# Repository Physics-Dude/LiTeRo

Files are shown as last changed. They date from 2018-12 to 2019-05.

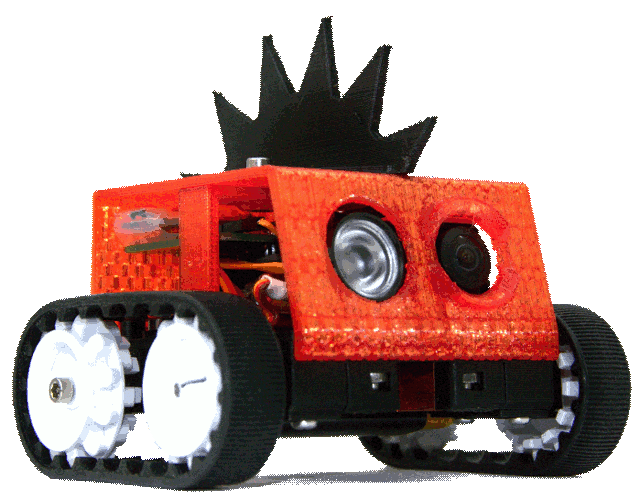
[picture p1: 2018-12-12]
html/robot.png

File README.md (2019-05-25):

# LiTeRo
## LiTeRo, the (Li)ttle (Te)lepresense (Ro)bot  

This python sketch is used in conjunction with phraser.php and litero.html to make a little RasPi-powered rover scoot around and do stuff.

#### Features included by default (Used GPIO pins also listed):
- MJPEG Streamer
  - 160-175deg Wide Angle Camera Module with White/IR LED modules For Raspberry Pi (Banggood)
- RPi.GPIO
  - HG7881 (L9110) Dual Channel Motor Driver (GPIO Pins 17, 18, 22, 27)
  - Navigation LED (2N2222 mod for White/IR LED module) (GPIO Pin 23)
  - Servo control! (Optional, not used by default. Pin 19)
- eSpeak Text-To-Speech
  - LM4871 audio amp conected to GPIO pin #13 (see: PWM1 on GPIO #13 (ALT0) for RasPi Zero W) 
- MinIMU-9 (I2C x2)
- ADS1115 ADC (Refer to Adafruit tutorials for setup) (I2C)
- sSMTP
	
#### Basic operation:
theprogram.py reads from a short text file in RAM (/dev/shm/input.txt) at about 60Hz with parameters that are set at will by a PHP script. The PHP script is being called as the client(s) send in new commands (ex: ./phraser.php?ID=546939&CT=1521479887886&M1=90&M2=90). The client in return gets an XML response that this Python program creates in RAM (/dev/shm/output.txt) along with an ongoing live view from the bot using MJPEG-Streamer. 
  
 LiTeRo by default will speak its local ip address on bootup. It will also guide you through the magnetic compass calibration when mag_calibration.txt is removed before bootup.

#### Things to prepare your Raspberry Pi or Raspberry Pi Zero
- For the Raspberry Pi Zero, you should enable audio out on one of the GPIO pins in order to use TTS (see: PWM1 on GPIO #13 (ALT0) for RasPi Zero W). 
- Make sure Apache, PHP, Python, SSMPT, mjpeg-streamer, eSpeak, and the Adafruit_ADS1x15 Python library are installed for FULL functionality. Other libaries may be present in the top of the python code.
- In the raspi-config; enable i2c, ssh, remote GPIO, and the camera. (uart is also useful if you want to configure the Pi without removing the SD card.)
- Make "thecode.py" run on startup. Put the following in /etc/rc.local
```
#my telepresence bot code
sleep 30s
sudo python /var/www/html/thecode.py &
```

 ###### More information can be found on thestuffwebuild.com
 ###### - Michael H.

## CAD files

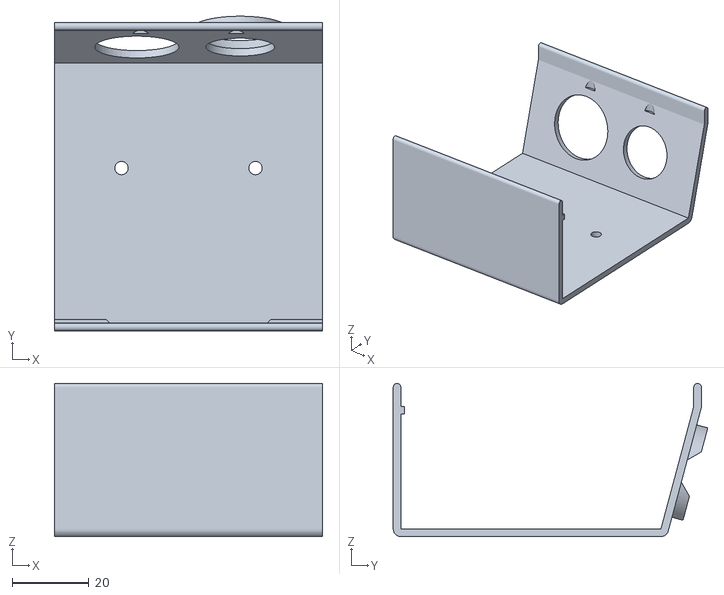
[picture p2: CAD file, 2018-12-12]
litero 3d files/Main - Outer Body Shell.stl
70.0 x 82.2 x 40.0

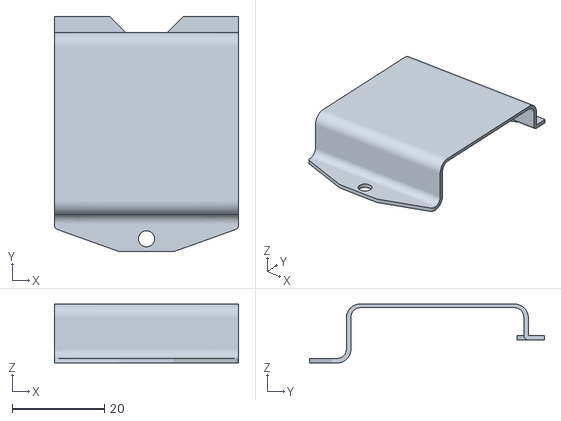
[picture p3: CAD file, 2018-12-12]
litero 3d files/Main - Battery Cover.stl
40.0 x 51.0 x 12.8

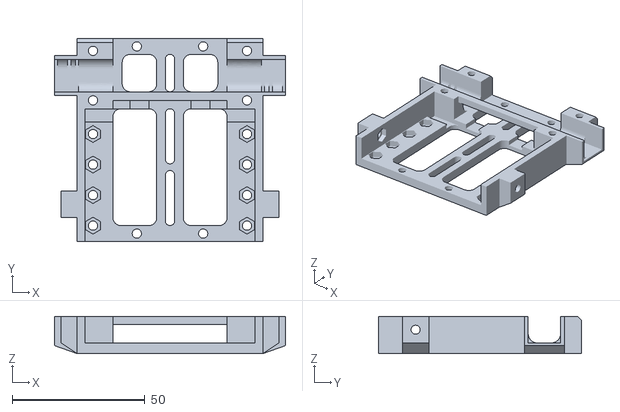
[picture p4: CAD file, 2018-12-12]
litero 3d files/Main - Chassis.stl
87.0 x 76.5 x 14.0

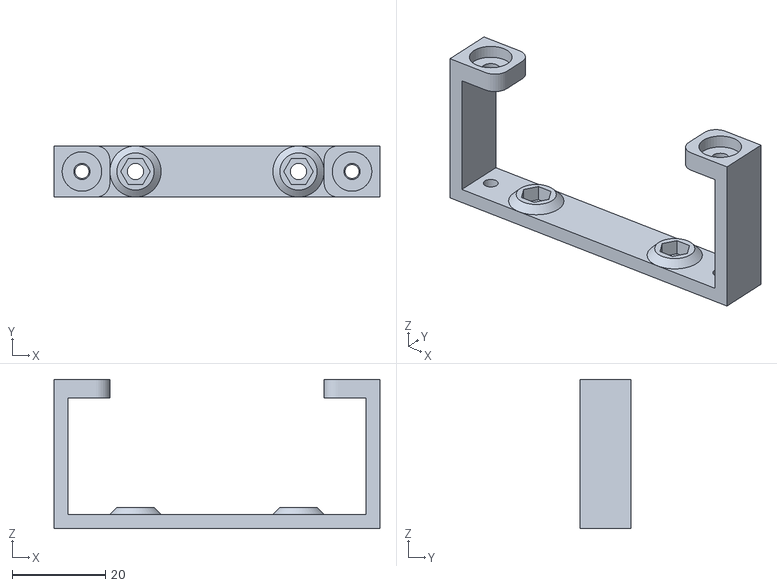
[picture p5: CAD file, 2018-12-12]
litero 3d files/Main - Roll Bar Body Mount.stl
70.0 x 11.0 x 32.0

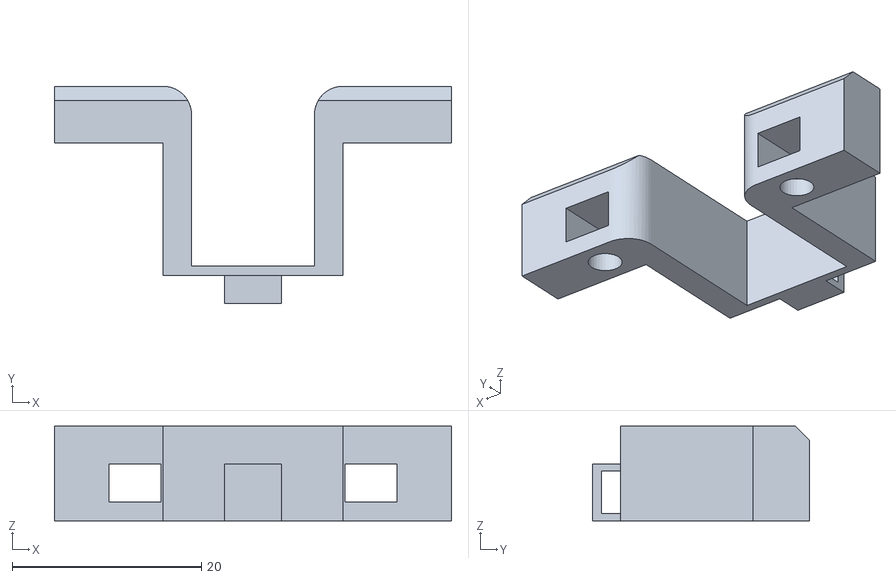
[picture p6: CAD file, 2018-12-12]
litero 3d files/Charge Dock - Bumper Contacts .stl
42.0 x 23.0 x 10.0

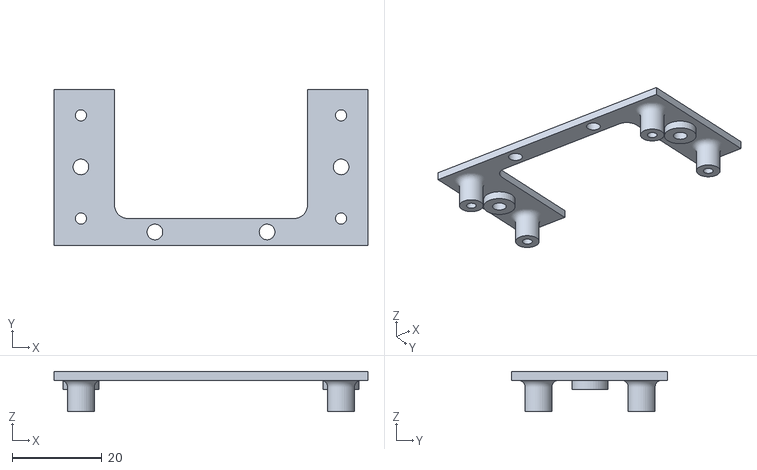
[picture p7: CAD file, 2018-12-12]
litero 3d files/Pi - Pi Zero Board Mount Plate.stl
70.0 x 34.8 x 9.00

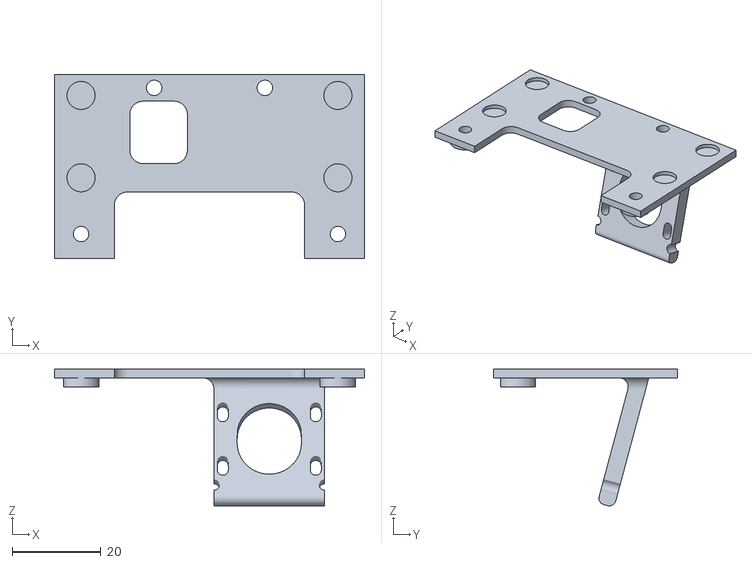
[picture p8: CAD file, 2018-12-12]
litero 3d files/Pi - Camera Mount Plate.stl
70.0 x 41.5 x 30.9

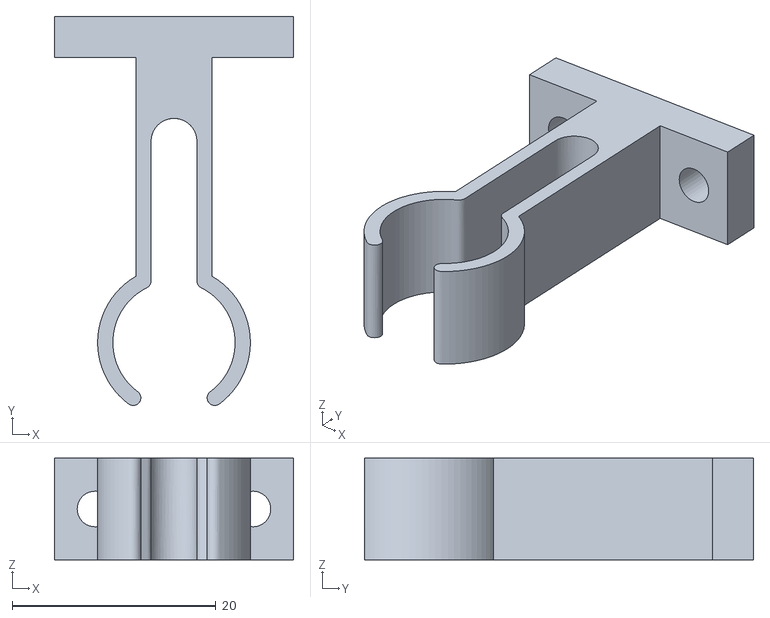
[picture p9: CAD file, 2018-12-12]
litero 3d files/Charge Dock - Contacts.stl
23.5 x 38.2 x 10.0

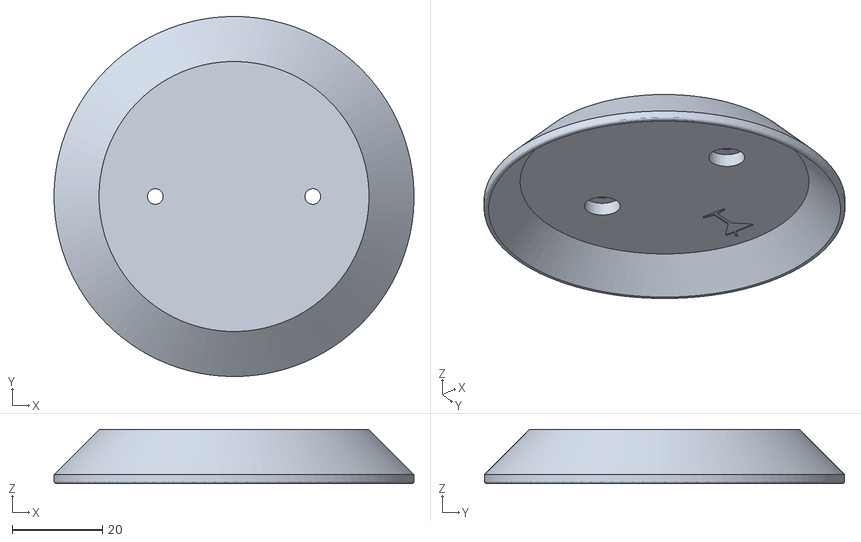
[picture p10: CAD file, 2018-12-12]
litero 3d files/Hat - Cup Holder.stl
80.0 x 80.0 x 12.0

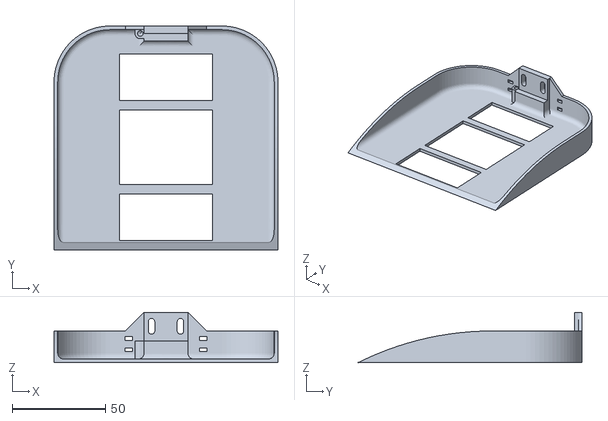
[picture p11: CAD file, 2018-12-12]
litero 3d files/Charge Dock - Pan.stl
120.0 x 120.0 x 27.0

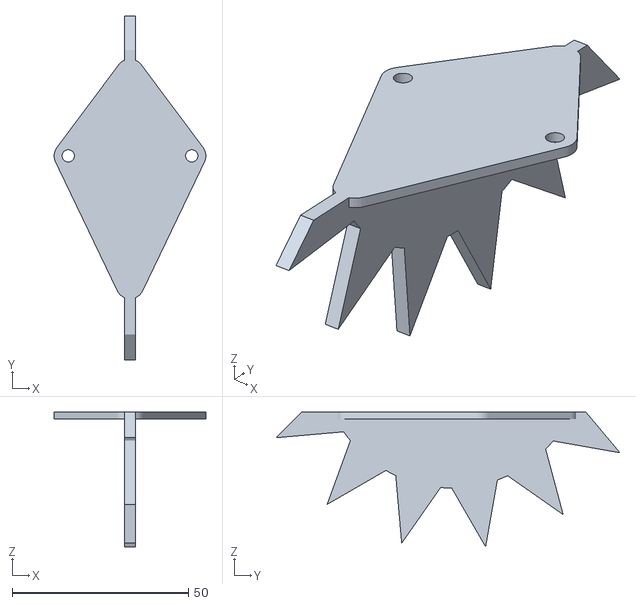
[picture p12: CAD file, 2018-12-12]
litero 3d files/Hat - Mohawk Anti-Tip.stl
43.0 x 97.5 x 38.2

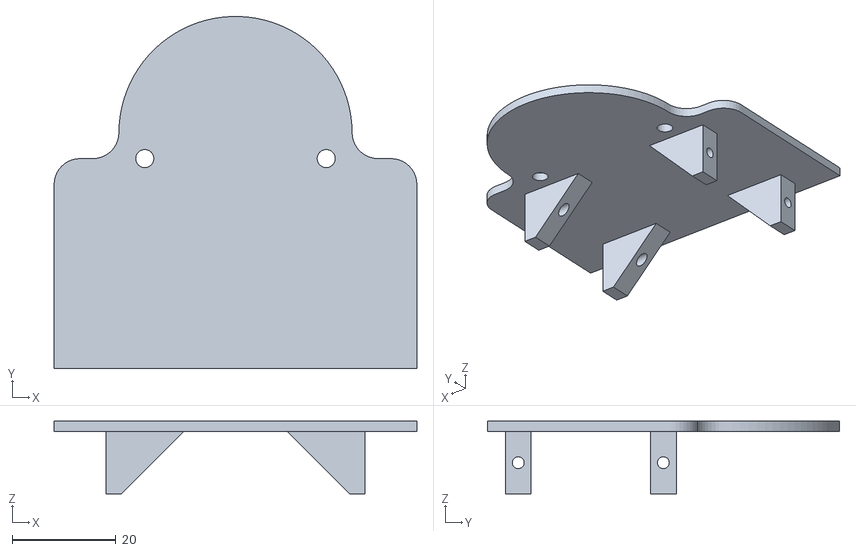
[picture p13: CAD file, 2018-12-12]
litero 3d files/Hat - Dual Servo.stl
70.0 x 67.9 x 14.0

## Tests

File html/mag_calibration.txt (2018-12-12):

6346,-7287,-6244,(X_offset | Y_Offset | Z_Offset)

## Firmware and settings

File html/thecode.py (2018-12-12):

'''
LiTeRo, the (Li)ttle (Te)lepresense (Ro)bot 

This python sketch is used in conjunction with phraser.php and litero.html to make a little RasPi-powered rover scoot around and do stuff.

Features included by default:
	- MJPEG Streamer
		- 160-175deg Wide Angle Camera Module with White/IR LED modules For Raspberry Pi (Banggood)
	- RPi.GPIO
		- HG7881 (L9110) Dual Channel Motor Driver (GPIO Pins 17, 18, 22, 27)
		- Navigation LED (2N2222 mod for White/IR LED module) (GPIO Pin 23)
	- eSpeak Text-To-Speech
		- LM4871 audio amp conected to GPIO pin #13 (see: PWM1 on GPIO #13 (ALT0) for RasPi Zero W) 
	- MinIMU-9 (I2C x2)
	- ADS1115 ADC (Refer to Adafruit tutorials for setup) (I2C)
	- sSMTP
	
Basic operation:
	This program reads from a short text file in RAM (/dev/shm/input.txt) at about 60Hz with parameters 
	that are set at will by a PHP script. The PHP script is being called as the client(s) send in new 
	requests (ex: ./phraser.php?ID=546939&CT=1521479887886&M1=90&M2=90). The client in return gets an XML 
	response that this Python program creates in RAM (/dev/shm/output.txt) along with an ongoing live view 
	from the bot using MJPEG-Streamer. 

More information can be found on thestuffwebuild.com
- Michael H.
'''

############## Begin Library Imports and User Setup ##############

# General purpose imports
import RPi.GPIO as GPIO
import os
import time
import math
import re
#import soul #Removed due to strange behavour.

# Import and config for MinIMU-9 comunication
import smbus 
bus = smbus.SMBus(1) #i2c buss these are on. 
LIS3MDL_M_ADDRESS		= 0x1E #LIS3MDL address
LSM6DS33_M_ADDRESS		= 0x6b #LSM6DS33 address
headingOffset = 180 # imu mount orientation offset. 
tippedOverFwdAngle = 60 # Max angle to determin if bot is propped up on its end.
tippedOverBakAngle = -60 # Min angle to determin if bot is propped up on its end.
useIMU = True #Change this to 'False' if you do not want to use an IMU

# Import and config for the ADS1x15 module.
import Adafruit_ADS1x15
adc = Adafruit_ADS1x15.ADS1115() # Create an ADS1115 ADC (16-bit) instance.
vCal = 1.062 # Manual calibration factor for volt readings:
aCal = 0.994 # Manual calibration factor for amp readings:
ADCAlpha = 0.1 # for running avgerage. Set to 1 to disable.
lowBattThresh = 3.5 #battery threshold for warnings
critBattThresh = 3.3 #shutdown if volts is below this for >15sec
useADC = True #Change this to 'False' if you do not want to use an ADC

# Audio and speech settings for systemSpeak() function
volume = 100
speechPitch=50 #pitch 0-99 (default = 50)
speechSpeed= 175 #speed 80wpm to 500wpm (default = 175wpm)
speechVoice= "en+m1" #try "en-f2". default = "en+m1"

# Email to deliever initialization and distress emails to:
ssmtp_To_email = "thestuffwebuild@gmail.com"

# Do you want to send an email on boot?
sendEmailOnBoot = False

# Motor behavour
motorAlpha = 0.3 # Accelration parameter. Applies only if enableMotorAccel = True
motorMin = 15 #minimm PWM% of motor. prevents motionless pwm noise. anlyhting less turns motors off.
enableMotorAccel = True	
gracefulStop = True
reverseMotorOutputs = True #use this if you need to reverse all motor outputs.
reverseLeftRight = True #use this if you need to swap valuse for left and right motors.

# Aspect ratio of your rpi camera sensor (4/3 = 1.33333)
camAspectRatio = 1.33333 

# Debug level for terminal output
debugLevel = 0 # 0 = only important stuff, higher is more stuff. -1 disables all output (may de-debug).
def printLog(text, level=0):
	if level <= debugLevel:
		print(str("%.2f" % time.time()) + " - " + text)		

############## End Library Imports and User Setup ##############

############## Begin GPIO Setup ############### 

# Define GPIO pins
MC1A = 17 #motor controller pin 1A connection to this GPIO pin
MC1B = 18 #motor controller pin 1B connection to this GPIO pin
MC2A = 27 #motor controller pin 2A connection to this GPIO pin 
MC2B = 22 #motor controller pin 2B connection to this GPIO pin
NAVLED_PIN = 23 #led trigger pin connection to this GPIO pin
# LM4871 audio amp conected to GPIO pin #13 (see: PWM1 on GPIO #13 (ALT0) for RasPi Zero W) 
# SERVO_PIN = 19 #optional servo signal pin connected this GPIO pin

GPIO.setmode(GPIO.BCM)
GPIO.setwarnings(False)

GPIO.setup(MC1A,GPIO.OUT) #motor controller pin 1A
GPIO.setup(MC1B,GPIO.OUT) #motor controller pin 1B
GPIO.setup(MC2A,GPIO.OUT) #motor controller pin 2A
GPIO.setup(MC2B,GPIO.OUT) #motor controller pin 2B
a = GPIO.PWM(MC1A, 1000)    # create an object p for PWM on port 25 at 50 Hertsz 
b = GPIO.PWM(MC1B, 1000)    # create an object p for PWM on port 25 at 50 Hertz 
c = GPIO.PWM(MC2A, 1000)    # create an object p for PWM on port 25 at 50 Hertz 
d = GPIO.PWM(MC2B, 1000)    # create an object p for PWM on port 25 at 50 Hertz 
a.start(0)             # start the PWM on 0 percent duty cycle (off)
b.start(0)             # start the PWM on 0 percent duty cycle (off)
c.start(0)             # start the PWM on 0 percent duty cycle (off)
d.start(0)             # start the PWM on 0 percent duty cycle (off)

GPIO.setup(NAVLED_PIN,GPIO.OUT) #navled pin
GPIO.output(NAVLED_PIN,False) # Switch off pin NAVLED_PIN

#GPIO.setup(SERVO_PIN,GPIO.OUT) # servo pwm pin
#pwm=GPIO.PWM(SERVO_PIN, 50) # servo pwm rate
#pwm.start(0) # start pwm at zero

############## End GPIO Setup ##############

############## Begin Global vars ##############
# Flag lets a routine run once
runFirstLoop = True	

#Default camera specs on boot
oldcamY = 144
oldcamFPS = 15
oldcamQ = 10

#mag offsets pulled from file
MagXoffs=0
MagYoffs=0
MagZoffs=0

#IMU placeholder
xAngle=0
yAngle=0
heading=0

# smoothed motor values
m1Real=0
m2Real=0

#previous values
oldm1 = 0
oldm2 = 0
oldnavLED = 0
oldclientTime = 0
oldservoPos = 0
oldspeakPhr = ""

#past timing values
lastMoveTime = 0
lastDataOutTime = 0
preclientTime = 0
lastheartbeatTime = 0
lastLBattCheckTime = 0
lastLBattSpeakTime = 0
lastLBattEmailTime = 0
lastRSSICheckTime = 0
lastServoUpdate = 0

#low battery flags
lowBatt = 0 
lowBattStrikes = 0

#this is sent to client and used for other things
camHASH=0
RSSI=0
RAamps=0
RAvolts=0

#user id control.
IDBase=["C137"]
UserID = 0
lastPurgeTime=0

#camera control
ranOnce = False
cameraKilled=0
lastIdleCheckTime=0

#open or make an input file in RAM
try:
	with open("/dev/shm/input.txt", "r") as filestream:
		printLog("Input file found",1)
except:
	os.system("echo 0,0,0,0,0,0,0,0,0,0,0,0,0,0,0,0,0,0,0,0,0, > /dev/shm/input.txt")
	os.system("sudo chown www-data:www-data /dev/shm/input.txt")
	printLog("Input file created",1)

############## End Global Vars ##############

############## Begin Function Defines ##############

#Text To Speech function
def systemSpeak(phrase, wait=0): #if second var is == 1, system will wait for phrase to finish before continuing (useful for initialization params)
	espeakCmds = "-v" + str(speechVoice)+" -p"+str(speechPitch)+" -s"+str(speechSpeed)
	
	printLog("Now speaking: "+str(phrase), 1) 
	
	if wait == 0:
		os.system("espeak "+str(espeakCmds)+" \""+str(phrase)+"\" 2>/dev/null&")
	else:
		os.system("espeak "+str(espeakCmds)+" \""+str(phrase)+"\" 2>/dev/null")
	#more espeak commands here: http://espeak.sourceforge.net/commands.html

# Magnetometer stuff
magInit = 0
def readMag(axis=''):
	# initialize mag if first run
	global magInit
	if magInit == 0:
		magInit = 1
		
		# initMag -- Sets up the magnetometer to begin reading.
		LIS3MDL_CTRL_REG1_M		= 0x20
		LIS3MDL_CTRL_REG2_M		= 0x21
		LIS3MDL_CTRL_REG3_M		= 0x22
		LIS3MDL_CTRL_REG4_M		= 0x23
		LIS3MDL_REG_CTL_1_TEMP_EN 	= 0x80
		LIS3MDL_REG_CTL_2_RESET 	= 0x04
		
		#User Register Reset Function
		bus.write_byte_data(LIS3MDL_M_ADDRESS, LIS3MDL_CTRL_REG2_M, LIS3MDL_REG_CTL_2_RESET)
		#Temperature Sensor Enabled
		bus.write_byte_data(LIS3MDL_M_ADDRESS, LIS3MDL_CTRL_REG1_M, LIS3MDL_REG_CTL_1_TEMP_EN )
		#Ultra High Performance Mode Selected for XY Axis
		bus.write_byte_data(LIS3MDL_M_ADDRESS, LIS3MDL_CTRL_REG1_M, 0x60)
		#Ultra High Performance Mode Selected for Z Axis
		bus.write_byte_data(LIS3MDL_M_ADDRESS, LIS3MDL_CTRL_REG4_M, 0x0C)
		#Output Data Rate of 80 Hz Selected
		bus.write_byte_data(LIS3MDL_M_ADDRESS, LIS3MDL_CTRL_REG1_M, 0x1C)
		#Continous Conversion Mode,4 wire interface Selected 
		bus.write_byte_data(LIS3MDL_M_ADDRESS, LIS3MDL_CTRL_REG3_M, 0x00)
		# 16 guass Full Scale 
		bus.write_byte_data(LIS3MDL_M_ADDRESS, LIS3MDL_CTRL_REG2_M, 0x60)
		
	if axis=='x' or axis == 'X':
		# Reading the  Magnetometer X-Axis Values from the Register 
		LIS3MDL_OUT_X_L_M = 0x28
		LIS3MDL_OUT_X_H_M = 0x29
		Mag_l = bus.read_byte_data(LIS3MDL_M_ADDRESS,LIS3MDL_OUT_X_L_M)
		Mag_h = bus.read_byte_data(LIS3MDL_M_ADDRESS,LIS3MDL_OUT_X_H_M)
		Mag_total = (Mag_l | Mag_h <<8)
		return Mag_total  if Mag_total < 32768 else Mag_total - 65536
	
	elif axis=='y' or axis == 'Y':
		# Reading the  Magnetometer Y-Axis Values from the Register
		LIS3MDL_OUT_Y_L_M = 0x2A
		LIS3MDL_OUT_Y_H_M = 0x2B
		Mag_l = bus.read_byte_data(LIS3MDL_M_ADDRESS,LIS3MDL_OUT_Y_L_M)
		Mag_h = bus.read_byte_data(LIS3MDL_M_ADDRESS,LIS3MDL_OUT_Y_H_M)
		Mag_total = (Mag_l | Mag_h <<8)
		return Mag_total  if Mag_total < 32768 else Mag_total - 65536
	
	elif axis=='z' or axis == 'Z':
		# Reading the  Magnetometer Z-Axis Values from the Register
		LIS3MDL_OUT_Z_L_M = 0x2C
		LIS3MDL_OUT_Z_H_M = 0x2D
		Mag_l = bus.read_byte_data(LIS3MDL_M_ADDRESS,LIS3MDL_OUT_Z_L_M)
		Mag_h = bus.read_byte_data(LIS3MDL_M_ADDRESS,LIS3MDL_OUT_Z_H_M)
		Mag_total = (Mag_l | Mag_h <<8)
		return Mag_total  if Mag_total < 32768 else Mag_total - 65536
	
	else:
		printLog("Function readMag() incorrectly called.")
		return 0

# Calibrate mag. can be called any time
def magCalibration(): #reads mag for 30 sec and writes avgeraged max and min offsets to file	
	systemSpeak("Calibrating magnetometer. Please rotate me on all axis for 30 seconds.", 1)
	
	calStartTime = time.time()
	lastMagReadTime = 0
	
	xList = []
	yList = []
	zList = []
	
	while time.time() - calStartTime < 30: 
		if time.time() - lastMagReadTime > 0.0125: #limit to 80hz 0.0125
		
			#test if reading is 
			xList.extend([int(readMag('x'))])
			yList.extend([int(readMag('y'))])
			zList.extend([int(readMag('z'))])
		
			lastMagReadTime = time.time()
			
	#collect min and max		
	magXmax = max(xList)
	magYmax = max(yList)
	magZmax = max(zList)
	
	magXmin = min(xList)
	magYmin = min(yList)
	magZmin = min(zList)
	
	# calculate offsets (use n -= nOffset)
	MagXoffs = (magXmin + magXmax) /2 ;
	MagYoffs = (magYmin + magYmax) /2 ;
	MagZoffs = (magZmin + magZmax) /2 ;
	
	#write to calibration file to write.
	try:
		with open("/var/www/html/mag_calibration.txt", "w") as magCal_out:
			magCal_out.write(str(MagXoffs)+","+str(MagYoffs)+","+str(MagZoffs)+",(X_offset | Y_Offset | Z_Offset)")
			printLog("Magnetometer calibration written to file.")
	except:
		printLog("Can not save magnetometer calibration data.")
	
	#clear lists (for ram?)
	xList = []
	yList = []
	zList = []
	
	systemSpeak("Magnetometer calibration complete. Applying offsets.",1)
	magApplyOffsets()

# Apply mag offsets or callibrate and apply if no cal file present
def magApplyOffsets():
	global MagXoffs
	global MagYoffs
	global MagZoffs
	#read mag offsets file and save variables
	try:
		with open("/var/www/html/mag_calibration.txt", "r") as magCal_in:
			for line in magCal_in:
				currentline = line.split(",")
				try:
					MagXoffs = int(currentline[0])		
					MagYoffs = int(currentline[1])	
					MagZoffs = int(currentline[2])	
					printLog("Magnetometer offsets applied as (X | Y | Z): "+str(MagXoffs)+","+str(MagYoffs)+","+str(MagZoffs))	
				except:
					printLog("Bad magnetometer calibration file. No offsets applied.")
					
	except:
		printLog("No magnetometer calibration file found. Starting magCalibration().")
		magCalibration()
if useIMU: magApplyOffsets()

# Accelrometer stuff
accInit = 0
def readAcc(axis=''):
	# initialize acc if first run
	global accInit
	if accInit == 0:
		accInit = 1

		# initAcc -- Sets up the Accnetometer to begin reading.
		LSM_CTRL1_XL          = 0x10  # [+] Acceleration sensor control
		LSM_CTRL2_G           = 0x11  # [+] Angular rate sensor (gyroscope) control
		LSM_CTRL3_C           = 0x12  # [+] Device/communication settings

		bus.write_byte_data(LSM6DS33_M_ADDRESS, LSM_CTRL3_C, 0x00)

		# Accelerometer
		# 1.66 kHz / +/- 4g
		# 01011000b
		bus.write_byte_data(LSM6DS33_M_ADDRESS, LSM_CTRL1_XL, 0x58)

		#turn off gyro, we don't need it.
		bus.write_byte_data(LSM6DS33_M_ADDRESS, LSM_CTRL2_G, 0x00)


	if axis=='x' or axis == 'X':
		# Reading the  Accnetometer X-Axis Values from the Register
		LSM6DS33_OUT_X_L_M		= 0x28
		LSM6DS33_OUT_X_H_M		= 0x29
		Acc_l = bus.read_byte_data(LSM6DS33_M_ADDRESS,LSM6DS33_OUT_X_L_M)
		Acc_h = bus.read_byte_data(LSM6DS33_M_ADDRESS,LSM6DS33_OUT_X_H_M)
		Acc_total = (Acc_l | Acc_h <<8)
		return Acc_total  if Acc_total < 32768 else Acc_total - 65536

	elif axis=='y' or axis == 'Y':
		# Reading the  Accnetometer Y-Axis Values from the Register
		LSM6DS33_OUT_Y_L_M		= 0x2A
		LSM6DS33_OUT_Y_H_M		= 0x2B
		Acc_l = bus.read_byte_data(LSM6DS33_M_ADDRESS,LSM6DS33_OUT_Y_L_M)
		Acc_h = bus.read_byte_data(LSM6DS33_M_ADDRESS,LSM6DS33_OUT_Y_H_M)
		Acc_total = (Acc_l | Acc_h <<8)
		return Acc_total  if Acc_total < 32768 else Acc_total - 65536

	elif axis=='z' or axis == 'Z':
		# Reading the  Accnetometer Z-Axis Values from the Register
		LSM6DS33_OUT_Z_L_M		= 0x2C
		LSM6DS33_OUT_Z_H_M		= 0x2D
		Acc_l = bus.read_byte_data(LSM6DS33_M_ADDRESS,LSM6DS33_OUT_Z_L_M)
		Acc_h = bus.read_byte_data(LSM6DS33_M_ADDRESS,LSM6DS33_OUT_Z_H_M)
		Acc_total = (Acc_l | Acc_h <<8)
		return Acc_total  if Acc_total < 32768 else Acc_total - 65536

	else:
		printLog("Function readAcc() incorrectly called.")
		return 0

# Gyro stuff
gyroInit = 0
def readGyro(axis=''):
	# Gyroscope dps/LSB for 1000 dps full scale
	GYRO_GAIN       = 0.035
	LSM6DS33_ADDR   = 0x6b
	
	# initialize gyro if first run
	global gyroInit
	if gyroInit == 0:
		gyroInit = 1
		LSM6DS33_CTRL2_G           = 0x11  # Angular rate sensor (gyroscope) control
		bus.write_byte_data(LSM6DS33_ADDR, LSM6DS33_CTRL2_G, 0x58)
		
		
	if axis=='x' or axis == 'X':
		#read gyro x
		LSM6DS33_OUTX_L_G          = 0x22  # Gyroscope pitch axis (X) output, low byte
		LSM6DS33_OUTX_H_G          = 0x23  # Gyroscope pitch axis (X) output, high byte
		Gyro_l = bus.read_byte_data(LSM6DS33_ADDR,LSM6DS33_OUTX_L_G)
		Gyro_h = bus.read_byte_data(LSM6DS33_ADDR,LSM6DS33_OUTX_H_G)
		Gyro_total = (Gyro_l | Gyro_h <<8)
		Gyro_total=Gyro_total   if Gyro_total < 32768 else Gyro_total - 65536
		return Gyro_total * GYRO_GAIN
	
	elif axis=='y' or axis == 'Y':
		#read gyro y
		LSM6DS33_OUTY_L_G          = 0x24  # Gyroscope roll axis (Y) output, low byte
		LSM6DS33_OUTY_H_G          = 0x25  # Gyroscope roll axis (Y) output, high byte
		Gyro_l = bus.read_byte_data(LSM6DS33_ADDR,LSM6DS33_OUTY_L_G)
		Gyro_h = bus.read_byte_data(LSM6DS33_ADDR,LSM6DS33_OUTY_H_G)
		Gyro_total = (Gyro_l | Gyro_h <<8)
		Gyro_total=Gyro_total   if Gyro_total < 32768 else Gyro_total - 65536
		return Gyro_total * GYRO_GAIN
	
	elif axis=='z' or axis == 'Z':
		#read gyro z
		LSM6DS33_OUTZ_L_G          = 0x26  # Gyroscope yaw axis (Z) output, low byte
		LSM6DS33_OUTZ_H_G          = 0x27  # Gyroscope yaw axis (Z) output, high byte
		Gyro_l = bus.read_byte_data(LSM6DS33_ADDR,LSM6DS33_OUTZ_L_G)
		Gyro_h = bus.read_byte_data(LSM6DS33_ADDR,LSM6DS33_OUTZ_H_G)
		Gyro_total = (Gyro_l | Gyro_h <<8)
		Gyro_total=Gyro_total   if Gyro_total < 32768 else Gyro_total - 65536
		return Gyro_total * GYRO_GAIN
	
	else:
		printLog("Function readGyro() incorrectly called.")
		return 0

# Temporarly disables GPIO if needed
def idle():
	a.ChangeDutyCycle(0)  
	b.ChangeDutyCycle(0)  
	c.ChangeDutyCycle(0)  
	d.ChangeDutyCycle(0)  
	GPIO.output(NAVLED_PIN,False)

# Email notification function for boot-up status and alarms	
lastEmailSentTime = 0 
def sendAnEmail():
	idle() # this could take a while. lets stop the motors for now.
	global lastEmailSentTime
	if time.time() - lastEmailSentTime > 60: #Don't send more than one email a minute
		printLog("Writing email...",1)
		bodytext = ""
		
		subtext = "Your little robot friend has something to say. - "+str(time.time())
		
		if lowBatt == 1:
			subtext = "HELP! Your little robot friend is in Distress! - "+str(time.time())
			bodytext += "My battery is pretty low now. I might shut down soon...\n\n" 
		
		bodytext += "Let me tell you about myself...\n\n"
		
		#write ADC vars
		bodytext += "Battery Volts: " + str(round(volts,2)) + "V\n" 
		bodytext += "Battery Amps: " + str(round(amps,2)) + "A\n\n" 
		
		# Write IMU data
		bodytext += "Accelorometer X angle (horizon=90deg): " + str(round(xAngle,2)) + "deg\n" 
		bodytext += "Accelorometer Y angle (horizon=90deg): " + str(round(yAngle,2)) + "deg\n" 
		bodytext += "Magnetometer heading: " + str(round(heading,2)) + "deg\n\n" 

		#write cpu temp
		netStat = os.popen("/opt/vc/bin/vcgencmd measure_temp").read()
		bodytext += "CPU " + str(netStat) + "\n"
		
		#write uptime
		netStat = os.popen("uptime").read()
		bodytext += "Uptime: " + str(netStat) + "\n" 

		#write lan status
		bodytext += "RSSI: " + str(RSSI) + "\n" 
		netStat = os.popen("ifconfig wlan0").read()
		bodytext += "LAN Status:\n" + str(netStat) + "\n\n"

		os.system("printf \"To: "+str(ssmtp_To_email)+"\nFrom: My little robot's name\nSubject: "+str(subtext)+"\n\n"+str(bodytext)+"\n\" | ssmtp -t")

		printLog("Email sent!")
		lastEmailSentTime = time.time()
	else:
		printLog("Email not sent. Please wait a bit before sending another.")

# Find a value between two strings
def find_between( s, first, last ):
    try:
        start = s.index( first ) + len( first )
        end = s.index( last, start )
        return s[start:end]
    except ValueError:
        return ""

# Servo controller (not used by default)
def setServoAngle(angle): # an angle <0 turns off servo to avoid jitter.
	if angle >= 0:
		duty = angle / 18 + 2
		GPIO.output(SERVO_PIN, True)
		pwm.ChangeDutyCycle(duty)
	else: 
		GPIO.output(SERVO_PIN, False)
		pwm.ChangeDutyCycle(0)

############## End Function Defines ##############

################ Main Loop ################
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
